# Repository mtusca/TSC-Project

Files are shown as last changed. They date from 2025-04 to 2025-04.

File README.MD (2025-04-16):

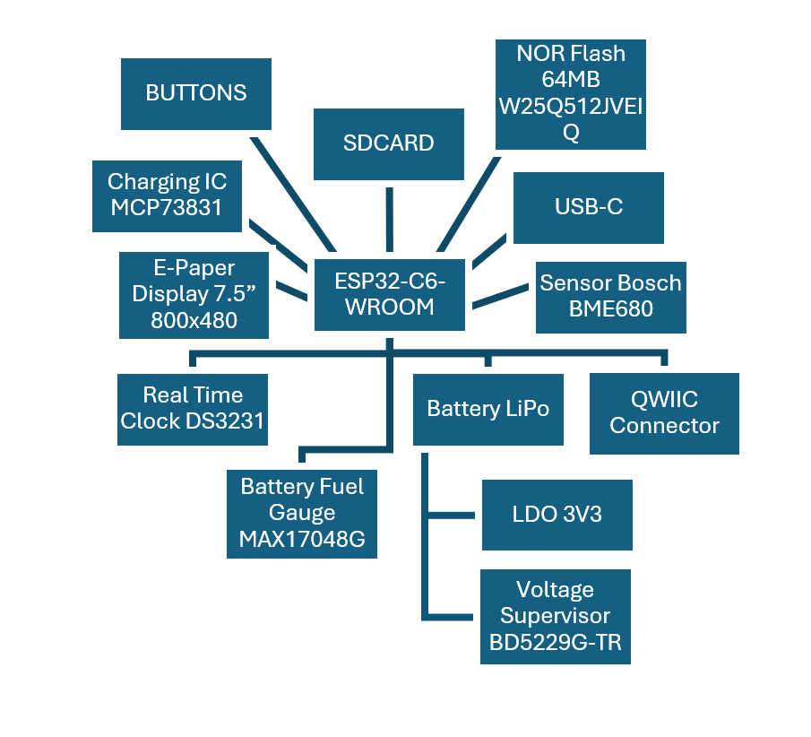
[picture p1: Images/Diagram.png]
Diagram


E-readerul implementat integrează mai multe module esențiale, inclusiv ESP32-C6, un modul RTC, senzori de mediu, 
conectivitate USB-C, un slot pentru card MicroSD și un sistem de gestionare a bateriei. 
Toate componentele comunică prin interfețe standard precum I²C, SPI, UART și GPIO analogice/digitale.

Controler de încărcare – MCP73831
Tip baterie: Li-ion/Li-Po cu o singură celulă

Curent de încărcare: Programabil până la 500 mA

Interfață: Standalone (fără I²C/SPI)

Tensiune de intrare: 3.75 V – 6 V

Ieșire stare: Indicație a stării de încărcare prin LED

Senzor de mediu – BME688
Măsurători: Temperatură, umiditate, presiune, gaze (VOC, calitatea aerului)

Interfață: I²C, SPI

Interval temperatură: -40 °C – +85 °C

Senzor de gaze: Detecție AI a amestecurilor de gaze și VOC

Consum de energie: Ultra redus (ideal pentru dispozitive mobile/wearables)

Display e-paper
Interfață: SPI

Rezoluție: 800×480

Consum de energie: Foarte redus (consum doar în timpul actualizării)

Caracteristici: Lizibil excelent în lumină solară, unghiuri largi de vizualizare

Conector Qwiic
Tip: Conector JST SH cu 4 pini (1.0 mm)

Scop: Interconectare I²C standardizată pentru senzori/module

Tensiune: Logică de 3.3 V

Pini: SDA, SCL, VCC, GND

Conector card memorie – 112A-TAAR-R03
Tip: Slot pentru card MicroSD

Interfață: SPI sau SDIO

Tensiune: Logică 3.3 V

Caracteristici: Mecanism push-push, contact pentru detectare card

Utilizare: Stocare de date, redare media

Microcontroler – ESP32-C6-WROOM-1-N8
Procesor: RISC-V pe 32 de biți, până la 160 MHz

Memorie: 512 KB SRAM intern, 8 MB flash extern (W25Q512JVEIQ)

Conectivitate: Wi-Fi 6 (802.11ax), Bluetooth 5 (LE), IEEE 802.15.4 (Thread/Zigbee), USB 2.0 (Full-Speed)

Periferice: SPI, I²C, UART, PWM, ADC, mai mulți pini GPIO

Memorie externă – W25Q512JVEIQ
Capacitate: 512 Mbit (64 MB)

Interfață: Quad SPI (QPI)

Frecvență de operare: Până la 133 MHz

Tensiune de alimentare: 2.7 V – 3.6 V

Caracteristici: rezistență mare (100.000 cicluri scriere/ștergere)

Ceas în timp real – DS3231SN#
Precizie: ±2 ppm între 0°C și +40°C

Interfață: I²C

Caracteristici: Oscilator cu cristal compensat termic (TCXO) integrat

Tensiune de funcționare: 2.3 V – 5.5 V

Funcționalități suplimentare: suport pentru baterie de rezervă, 2 alarme programabile, ieșire pătrată 1Hz

Monitor baterie – MAX17048G+T10
Funcție: Indicator de încărcare pentru baterii Li-ion/Li-Po cu o singură celulă

Interfață: I²C

Tensiune: 2.5 V – 4.5 V

Consum de putere: Curent de repaus ultra-redus (~23 µA)

<pre lang="markdown"> 
ESP32-C6 Pin description
  EN -> Resets the MCU
  IO0 - INT_RTC -> Used to receive interrupts signals from RTC, allowing for two major functionalities: Alarm and Square Wave Output
  IO1 - 32KHz -> Used for a stable clock signal of 32.768 kHz generated by the RTC
  IO2 – MISO -> Master In Slave Out Signal, used in the SPI communication with the SD Card
  IO3 - EPD_BUSY -> Indicates display driver status
  IO4 – SS_SD -> Chip select for SPI communication with SD Card
  IO5 – EPD_DC -> Display serial communication Command/Data input
  IO6 – SCK -> Clock signal for I2C communication
  IO7 – MOSI -> Master Out Slave In Signal, used to send data to display and SD Card
  IO8 - GPIO8 - Controls MCU boot mode
  IO9 - IO/BOOT -> Used to detect BOOT button press
  NC -> Not connected
  3V3 -> Used to power the MCU and the other components
  IO10 - EPD_CS -> Chip select for SPI serial communication with the display
  IO11 - FLASH_CS -> Chip select for SPI communication with the flash
  IO12 - USB_D- -> Used in USB differential communication
  IO13 - USB_D+ -> Used in USB differential communication
  IO15 - IO/CHANGE -> Used to detect CHANGE button press
  TXD0/GPIO16 - TX -> Sends data to another device via UART
  RXD0/GPIO17 - RX -> Receives data from another device via UART
  IO18 - RTC_RST -> Resets the RTC
  IO19 - I2C_PW -> Power source for I2C components
  IO20 - EPD_3V3_C -> Display IO voltage supply
  IO21 - SDA -> Used to send and receive data in the I2C communication with the sensor, RTC module and Battery Fuel Gauge
  IO22 - SCL -> Clock signal for I2C communication
  IO23 - EPD_RST -> Global reset signal for the display
  GND -> Shared Voltage Reference
</pre>

[📋 Download BoM](./Manufacturing/Bill%20of%20Materials.csv)

|Component |Footprint |Link |
|---|---|---|
|BOOT_BUTTON  |BUTTON_CUSYOMV1 |https://industry.panasonic.com/global/en/products/control/switch/light-touch/number/evqpuj02k |
|C1 |ESP32_WROVER_EAGLE-LTSPICE_CC0402 |https://eu.mouser.com/ProductDetail/YAGEO/CC0402MRX5R5BB106?qs=zEY9bCHj09eCmUJdZuS5Lg%3D%3D |
|C1_BAT |ESP32_WROVER_EAGLE-LTSPICE_CC0402 |n/a |
|C1_BAT1 |EAGLE-LTSPICE_CC0402 |n/a |
|C1_BAT2 |EAGLE-LTSPICE_CC0402 |n/a |
|C2 |ESP32_WROVER_EAGLE-LTSPICE_CC0402 |n/a |
|C2_BAT\ |ESP32_WROVER_EAGLE-LTSPICE_CC0402 |n/a |
|C3 |RCL_CPOL-EUCT3528 |n/a |
|C4 |ESP32_WROVER_EAGLE-LTSPICE_CC0402 |n/a |
|C4_USB |ESP32_WROVER_EAGLE-LTSPICE_CC0402 |n/a |
|C5 |ESP32_WROVER_EAGLE-LTSPICE_CC0402 |n/a |
|C5_USB |ESP32_WROVER_EAGLE-LTSPICE_CC0402 |n/a |
|C6 |ESP32_WROVER_EAGLE-LTSPICE_CC0402 |n/a |
|C7 |ESP32_WROVER_EAGLE-LTSPICE_CC0402 |n/a |
|C8 |ESP32_WROVER_EAGLE-LTSPICE_CC0402 |n/a |
|C9 |EAGLE-LTSPICE_CC0402 |n/a |
|C10 |ESP32_WROVER_EAGLE-LTSPICE_CC0402 |n/a |
|C10_SUPERCAP |CPH3225A |https://www.snapeda.com/parts/CPH3225A/Seiko+Instruments/view-part/?ref=eda |
|CHANGE_BUTTON|BUTTON_CUSYOMV1 |https://industry.panasonic.com/global/en/products/control/switch-light-touch/number/evqpuj02k |
|CHG_LED |ADAFRUIT_LEDCHIP-LED0603 |https://www.snapeda.com/parts/KP-1608SURCK/Kingbright/view-part/?ref=search&t=LED%200603 |
|C_DELAY |ESP32_WROVER_EAGLE-LTSPICE_CC0402 |n/a |
|D1 |USBLC6-2SC6Y |https://www.snapeda.com/parts/USBLC6-2SC6Y/STMicroelectronics/view-part/?ref=eda |
|D2 |ESP32_WROVER_AVX---SD0805S020S1R0_AVX_... |https://eu.mouser.com/ProductDetail/KYOCERA-AVX/SD0805S020S1R0?qs=jCA%252BPfw4LHbpkAoSnwrdjw%3D%3D |
|D3 |MBR0530 |https://eu.mouser.com/ProductDetail/KYOCERA-AVX/SD0805S020S1R0?qs=jCA%252BPfw4LHbpkAoSnwrdjw%3D%3D |
|D4 |MBR0530 |https://www.snapeda.com/parts/MBR0530/Onsemi/view-part/?ref=eda |
|D5 |MBR0530 |https://www.snapeda.com/parts/MBR0530/Onsemi/view-part/?ref=eda |
|D6 |PGB1010603MR |https://www.snapeda.com/parts/PGB1010603MR/Littelfuse/view-part/?ref=eda |
|D7 |ESP32_WROVER_AVX---SD0805S020S1R0_AVX_... |https://eu.mouser.com/ProductDetail/KYOCERA-AVX/SD0805S020S1R0?qs=jCA%252BPfw4LHbpkAoSnwrdjw%3D%3D |
|D8 |PGB1010603MR |https://www.snapeda.com/parts/PGB1010603MR/Littelfuse/view-part/?ref=eda |
|D9 |PGB1010603MR |https://www.snapeda.com/parts/PGB1010603MR/Littelfuse/view-part/?ref=eda |
|D10 |PGB1010603MR |https://www.snapeda.com/parts/PGB1010603MR/Littelfuse/view-part/?ref=eda |
|D11 |PGB1010603MR |https://www.snapeda.com/parts/PGB1010603MR/Littelfuse/view-part/?ref=eda |
|D12 |PGB1010603MR |https://www.snapeda.com/parts/PGB1010603MR/Littelfuse/view-part/?ref=eda |
|EPD_C1 |ESP32_WROVER_EAGLE-LTSPICE_CC0402 |n/a |
|EPD_C2 |ESP32_WROVER_EAGLE-LTSPICE_CC0402 |n/a |
|EPD_C5 |ESP32_WROVER_EAGLE-LTSPICE_CC0402 |n/a |
|EPD_C6 |ESP32_WROVER_EAGLE-LTSPICE_CC0402 |n/a |
|EPD_C7 |ESP32_WROVER_EAGLE-LTSPICE_CC0402 |n/a |
|EPD_C8 |ESP32_WROVER_EAGLE-LTSPICE_CC0402 |n/a |
|EPD_C9 |ESP32_WROVER_EAGLE-LTSPICE_CC0402 |n/a |
|EPD_C10 |ESP32_WROVER_EAGLE-LTSPICE_CC0402 |n/a |
|EPD_C11 |ESP32_WROVER_EAGLE-LTSPICE_CC0402 |n/a |
|EPD_C12 |ESP32_WROVER_EAGLE-LTSPICE_CC0402 |n/a |
|IC1 |BD5229G-TR |https://componentsearchengine.com/part-view/BD5229G-TR/ROHM%20Semiconductor |
|IC4 |XC6220A331MR-G |https://componentsearchengine.com/part-view/XC6220A331MR-G/Torex |
|J1 |FH34SRJ-24S-0.5SH_99_ |https://componentsearchengine.com/part-view/XC6220A331MR-G/Torex |
|J2 |SAMACSYS_PARTS_USB4110-GF-A |https://componentsearchengine.com/part-view/USB4110-GF-A/GCT%20(GLOBAL%20CONNECTOR%20TECHNOLOGY |
|J3 |QWIIC_CONNECTORJS-1MM |n/a |
|J4 |112A-TAAR-R03_ATTEND |https://store.comet.srl.ro/Catalogue/Product/43497/ |
|L1 |744043680IND_4828-WE-TPC_WRE |https://eu.mouser.com/ProductDetail/Wurth-Elektronik/744043680?qs=PGXP4M47uW6VkZq%252BkzjrHA%3D%3D |
|PFMF.050.1 |ESP32C6_VARISTORCN1812 |https://www.mouser.co.uk/ProductDetail/EPCOS-TDK/B72520T0350K062?qs=dEfas%2FXlABIszF52uu7vrg%3D%3D |
|Q1 |ESP32_WROVER_SPARKFUN-DISCRETESEMI_MOSFET_...|https://componentsearchengine.com/part-view/DMG2305UX-7/Diodes%20Incorporated |
|Q2 |ESP32_WROVER_SPARKFUN-DISCRETESEMI_MOSFET_...|n/a |
|Q3 |D8 |https://componentsearchengine.com/part-view/SI1308EDL-T1-GE3/Vishay |
|R1 |ESP32_WROVER_EAGLE-LTSPICE_RR0402 |n/a |
|R1-PINH |ESP32_WROVER_EAGLE-LTSPICE_RR0402 |n/a |
|R1-PINH1 |ESP32_WROVER_EAGLE-LTSPICE_RR0402 |n/a |
|R1_BAT |ESP32_WROVER_EAGLE-LTSPICE_RR0402 |n/a |
|R1_PWRUSB |ESP32_WROVER_EAGLE-LTSPICE_RR0402 |n/a |
|R2 |ESP32_WROVER_EAGLE-LTSPICE_RR0402 |https://componentsearchengine.com/part-view/R0402%201%25%20100%20K%20(RC0402FR-07100KL |
|R2-PINH |ESP32_WROVER_EAGLE-LTSPICE_RR0402 |n/a |
|R2-PINH1 |ESP32_WROVER_EAGLE-LTSPICE_RR0402 |n/a |
|R2-USB |ESP32_WROVER_EAGLE-LTSPICE_RR0402 |n/a |
|R2-USB1 |ESP32_WROVER_EAGLE-LTSPICE_RR0402 |n/a |
|R2_BAT |ESP32_WROVER_EAGLE-LTSPICE_RR0402 |n/a |
|R3 |ESP32_WROVER_EAGLE-LTSPICE_RR0402 |n/a |
|R4 |ESP32_WROVER_EAGLE-LTSPICE_RR0402 |n/a |
|R5 |ESP32_WROVER_EAGLE-LTSPICE_RR0402 |n/a |
|R6 |ESP32_WROVER_EAGLE-LTSPICE_RR0402 |n/a |
|R7 |ESP32_WROVER_EAGLE-LTSPICE_RR0402 |n/a |
|R8 |ESP32_WROVER_EAGLE-LTSPICE_RR0402 |n/a |
|R9 |ESP32_WROVER_EAGLE-LTSPICE_RR0402 |n/a |
|R10 |ESP32_WROVER_EAGLE-LTSPICE_RR0402 |n/a |
|RESET_BUTTON |BUTTON_CUSYOMV1 |https://industry.panasonic.com/global/en/products/control/switch/light-touch/number/evqpuj02k |
|R_BOOT |ESP32_WROVER_EAGLE-LTSPICE_RR0402 |n/a |
|R_CAPACITOR  |ESP32_WROVER_EAGLE-LTSPICE_RR0402 |n/a |
|R_CHANGE |ESP32_WROVER_EAGLE-LTSPICE_RR0402 |n/a |
|R_CL1 |ESP32_WROVER_EAGLE-LTSPICE_RR0402 |n/a |
|R_RESET |ESP32_WROVER_EAGLE-LTSPICE_RR0402 |n/a |
|SENSOR2 |ESP32_WROVER_BME680_BME680 |https://www.snapeda.com/parts/BME680/Bosch/view-part/?welcome=home |
|SJ1 |SJ |https://grabcad.com/library/solder-jumpers-1 |
|U1 |W25Q512JVEIQ |https://www.snapeda.com/parts/W25Q512JVEIQ/Winbond+Electronics/view-part/?ref=eda |
|U2 |ESP32-C6-WROOM-1-N8 |https://www.snapeda.com/parts/ESP32-C6-WROOM-1-N8/Espressif+Systems/view-part/?ref=eda |
|U3 |DS3231SN# |https://www.snapeda.com/parts/DS3231SN%23/Analog+Devices/view-part/?ref=eda |
|U4 |MAX17048G+T10 |https://www.snapeda.com/parts/MAX17048G+T10/Analog+Devices/view-part/?ref=eda |
|U5 |ESP32_WROVER_SPARKFUN-IC-POWER_MCP73831 |https://eu.mouser.com/ProductDetail/Microchip-Technology/MCP73831T-2ACI-OT?qs=yUQqVecv4qvbBQBGbHx0Mw%3D%3Dcf|

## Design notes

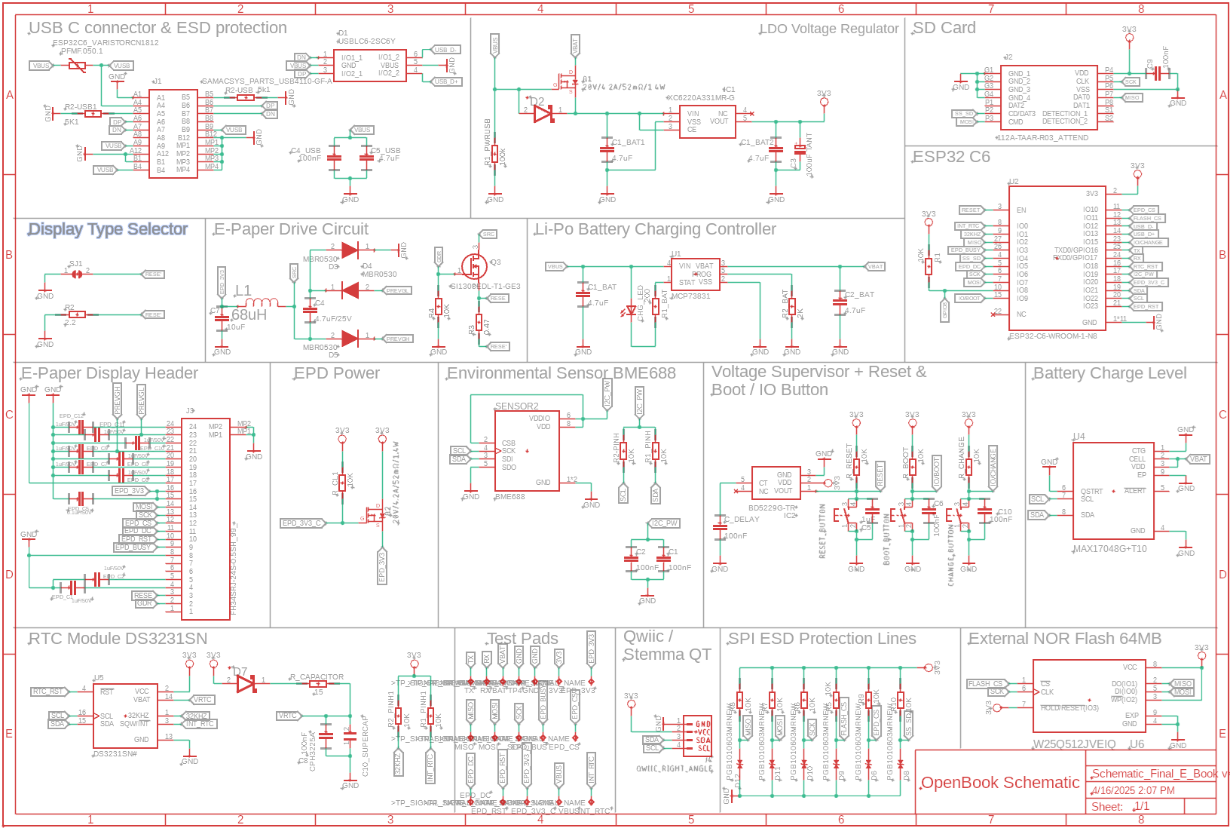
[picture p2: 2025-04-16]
Images/Schematic.png

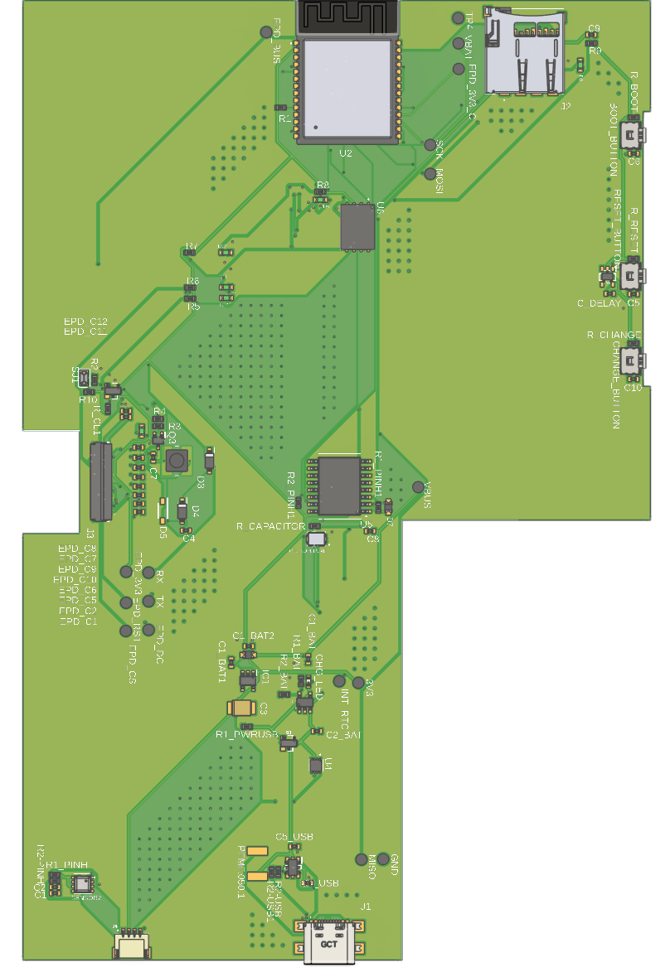
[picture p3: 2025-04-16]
Images/3D_PCB.png

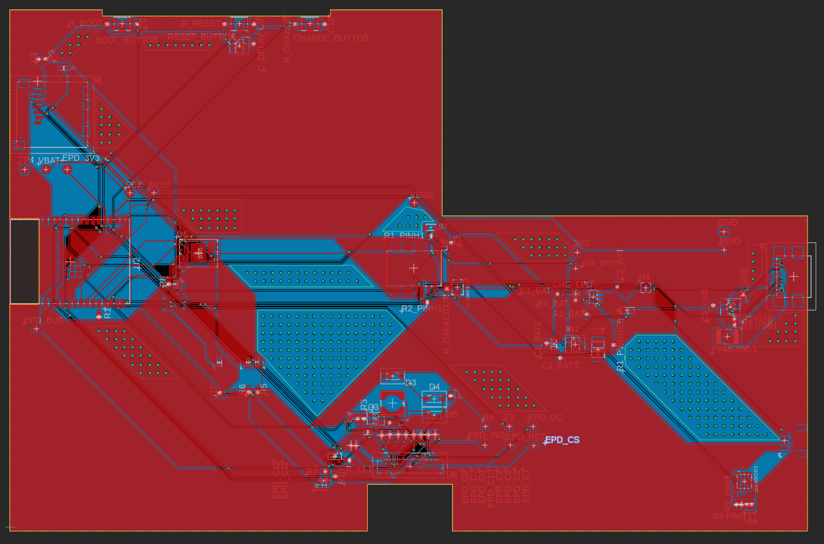
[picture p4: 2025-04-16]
Images/PCB.png

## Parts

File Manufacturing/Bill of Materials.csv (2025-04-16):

Qty | Value | Device | Package | Parts | Description | ARROW_PART_NUMBER | ARROW_PRICE-STOCK | AVAILABILITY | CENTROID_NOT_SPECIFIED | CHECK_PRICES | COPYRIGHT | DATASHEET | DESCRIPTION | DIGIKEY_DESCRIPTION | DIGIKEY_PART_NUMBER | HEIGHT | LEAD_FREE | MANUFACTURER_NAME | MANUFACTURER_PART_NUMBER | MF | MFR_NAME | MOUSER_PART_NUMBER | MOUSER_PRICE-STOCK | MOUSER_TESTING_PART_NUMBER | MOUSER_TESTING_PRICE-STOCK | MP | MPN | PACKAGE | POPULARITY | PREFIX | PRICE | PROD_ID | PURCHASE-URL | ROHS | SNAPEDA_LINK | SPICEPREFIX | TEMPERATURE_RANGE_HIGH | TEMPERATURE_RANGE_LOW | VALUE
1 |  | ADAFRUIT_LEDCHIP-LED0603 | ADAFRUIT_CHIP-LED0603 | CHG_LED | LED
1 |  | SJ | SJ | SJ1 | SMD solder JUMPER |  |  |  |  |  |  |  |  |  |  |  |  |  |  |  |  |  |  |  |  |  |  |  | 3
1 | 0.1uF/50V | ESP32_WROVER_EAGLE-LTSPICE_C | ESP32_WROVER_EAGLE-LTSPICE_C0402 | EPD_C5 | CAPACITOR, European symbol
1 | 0.47 | ESP32_WROVER_EAGLE-LTSPICE_R | ESP32_WROVER_EAGLE-LTSPICE_R0402 | R3 | RESISTOR, European symbol
1 | 100k | ESP32_WROVER_EAGLE-LTSPICE_R | ESP32_WROVER_EAGLE-LTSPICE_R0402 | R1_PWRUSB | RESISTOR, European symbol
8 | 100nF | ESP32_WROVER_EAGLE-LTSPICE_C | ESP32_WROVER_EAGLE-LTSPICE_C0402 | C1, C2, C4_USB, C6, C8, C9, C10, C_DELAY | CAPACITOR, European symbol
1 | 100uF TANT | RCL_CPOL-EUCT3528 | RCL_CT3528 | C3 | POLARIZED CAPACITOR, European symbol |  |  |  |  |  |  |  |  |  |  |  |  |  |  |  |  |  |  |  |  |  |  |  | 0 |  |  |  |  |  |  | C
16 | 10K | ESP32_WROVER_EAGLE-LTSPICE_R | ESP32_WROVER_EAGLE-LTSPICE_R0402 | R1, R1_PINH, R1_PINH1, R2-PINH, R2_PINH1, R4, R5, R6, R7, R8, R9, R10, R_BOOT, R_CHANGE, R_CL1, R_RESET | RESISTOR, European symbol
1 | 10uF | ESP32_WROVER_EAGLE-LTSPICE_C | ESP32_WROVER_EAGLE-LTSPICE_C0402 | C7 | CAPACITOR, European symbol
1 | 112A-TAAR-R03_ATTEND | 112A-TAAR-R03_ATTEND | 112ATAARR03ATTEND | J2 | Micro SD Card Socket, Push-Push Type, Top Mount, SMT, H=1.83mm, 10u |  |  |  |  |  |  |  | Micro SD Card Socket | Push-Push Type | Top Mount | SMT | H=1.83mm | 10u |  |  | 1.9mm |  | ATTEND | 112A-TAAR-R03 ATTEND
1 | 15 | ESP32_WROVER_EAGLE-LTSPICE_R | ESP32_WROVER_EAGLE-LTSPICE_R0402 | R_CAPACITOR | RESISTOR, European symbol
1 | 1uF | ESP32_WROVER_EAGLE-LTSPICE_C | ESP32_WROVER_EAGLE-LTSPICE_C0402 | C5 | CAPACITOR, European symbol
9 | 1uF/50V | ESP32_WROVER_EAGLE-LTSPICE_C | ESP32_WROVER_EAGLE-LTSPICE_C0402 | EPD_C1, EPD_C2, EPD_C6, EPD_C7, EPD_C8, EPD_C9, EPD_C10, EPD_C11, EPD_C12 | CAPACITOR, European symbol
1 | 2.2 | ESP32_WROVER_EAGLE-LTSPICE_R | ESP32_WROVER_EAGLE-LTSPICE_R0402 | R2 | RESISTOR, European symbol
1 | 200 | ESP32_WROVER_EAGLE-LTSPICE_R | ESP32_WROVER_EAGLE-LTSPICE_R0402 | R1_BAT | RESISTOR, European symbol
2 | 20V/4.2A/52m?/1.4W | ESP32_WROVER_SPARKFUN-DISCRETESEMI_MOSFET_PCH-DMG2305UX-7 | ESP32_WROVER_SPARKFUN-DISCRETESEMI_SOT23-3 | Q1, Q2 | P-channel MOSFETs |  |  |  |  |  |  |  |  |  |  |  |  |  |  |  |  |  |  |  |  |  |  |  |  |  |  | TRAN-14388 |  |  |  |  |  |  | 20V/4.2A/52m?/1.4W
1 | 2K | ESP32_WROVER_EAGLE-LTSPICE_R | ESP32_WROVER_EAGLE-LTSPICE_R0402 | R2_BAT | RESISTOR, European symbol
5 | 4.7uF | ESP32_WROVER_EAGLE-LTSPICE_C | ESP32_WROVER_EAGLE-LTSPICE_C0402 | C1_BAT, C1_BAT1, C1_BAT2, C2_BAT, C5_USB | CAPACITOR, European symbol
1 | 4.7uF/25V | ESP32_WROVER_EAGLE-LTSPICE_C | ESP32_WROVER_EAGLE-LTSPICE_C0402 | C4 | CAPACITOR, European symbol
1 | 5K1 | ESP32_WROVER_EAGLE-LTSPICE_R | ESP32_WROVER_EAGLE-LTSPICE_R0402 | R2-USB1 | RESISTOR, European symbol
1 | 5k1 | ESP32_WROVER_EAGLE-LTSPICE_R | ESP32_WROVER_EAGLE-LTSPICE_R0402 | R2-USB | RESISTOR, European symbol
1 | 68uH | 744043680IND_4828-WE-TPC_WRE | IND_4828-WE-TPC_WRE | L1 |  |  |  |  |  |  | Copyright (C) 2024 Ultra Librarian. All rights reserved. |  |  |  |  |  |  |  | 744043680 |  | Wurth Electronics
1 | BD5229G-TR | BD5229G-TR | SOT95P280X125-5N | IC2 | Voltage Detector with Adjustable Delay Time: CMOS processes are utilized to develop high precision, low current consumption CMOS reset ICs that allow arbitrary setting of the delay time. The extensive lineup includes both Nch Open Drain and CMOS output types in a wide range of detection voltages (from 2.3V to 6.0V, in 0.1V steps), enabling selection of the ideal solution based on customer requirements. In addition, the entire series is of course both lead-free and RoHS-compliant. |  |  |  |  |  |  |  | Voltage Detector with Adjustable Delay Time: CMOS processes are utilized to develop high precision | low current consumption CMOS reset ICs that allow arbitrary setting of the delay time. The extensive lineup includes both Nch Open Drain and CMOS output types in a wide range of detection voltages (from 2.3V to 6.0V | in 0.1V steps) | enabling selection of the ideal solution based on customer requirements. In addition | the entire series is of course both lead-free and RoHS-compliant. |  |  | 1.25mm |  | ROHM Semiconductor | BD5229G-TR |  |  | 755-BD5229G-TR | https://www.mouser.co.uk/ProductDetail/ROHM-Semiconductor/BD5229G-TR?qs=4kLU8WoGk0vvnhrrYwdszw%3D%3D
3 | BUTTON_CUSYOMV1NEW | BUTTON_CUSYOMV1NEW | MYBUTTON | BOOT_BUTTON, CHANGE_BUTTON, RESET_BUTTON
1 | CPH3225A | CPH3225A | CAPCP3225X100N | C10_SUPERCAP | Cap 0.011F 3.3V 1210 Flat Check availability |  |  | Not in stock |  | https://www.snapeda.com/parts/CPH3225A/Seiko+Instruments/view-part/?ref=eda |  |  | 11 mF (EDLC) Supercapacitor 3.3 V 1210 (3225 Metric) - - |  |  |  |  |  |  | Seiko Instruments |  |  |  |  |  | CPH3225A |  | 1210 Seiko |  |  | None |  | https://www.snapeda.com/api/url_track_click_mouser/?unipart_id=562593&manufacturer=Seiko Instruments&part_name=CPH3225A&search_term=None |  | https://www.snapeda.com/parts/CPH3225A/Seiko+Instruments/view-part/?ref=snap
1 | DS3231SN# | DS3231SN# | SOIC127P1032X265-16N | U5 | Real Time Clock Serial 16-Pin SOIC W T/R Check availability |  |  | In Stock |  | https://www.snapeda.com/parts/DS3231SN%23/Analog+Devices/view-part/?ref=eda |  |  | Extremely Accurate I?C-Integrated RTC/TCXO/Crystal |  |  |  |  |  |  | Analog Devices |  |  |  |  |  | DS3231SN# |  | SOIC-16 Maxim |  |  | None |  | https://www.snapeda.com/api/url_track_click_mouser/?unipart_id=99048&manufacturer=Analog Devices&part_name=DS3231SN#&search_term=None |  | https://www.snapeda.com/parts/DS3231SN%23/Analog+Devices/view-part/?ref=snap
1 | ESP32-C6-WROOM-1-N8 | ESP32-C6-WROOM-1-N8 | XCVR_ESP32-C6-WROOM-1-N8 | U2 | Check availability |  |  | In Stock |  | https://www.snapeda.com/parts/ESP32-C6-WROOM-1-N8/Espressif+Systems/view-part/?ref=eda |  |  | Multiprotocol Modules ESP32-C6 module | Wi-Fi 6 in 2.4 GHz band | Bluetooth 5 | Zigbee 3.0 and Thread. ESP34-WROOM Compatible - ENGINEERING SAMPLE |  |  |  |  |  |  | Espressif Systems |  |  |  |  |  | ESP32-C6-WROOM-1-N8 |  | None |  |  | None |  |  |  | https://www.snapeda.com/parts/ESP32-C6-WROOM-1-N8/Espressif+Systems/view-part/?ref=snap
1 | ESP32C6_VARISTORCN1812 | ESP32C6_VARISTORCN1812 | ESP32C6_VARISTOR_CT/CN1812 | PFMF.050.1 | VARISTOR |  |  |  |  |  |  |  |  |  |  |  |  |  |  |  |  |  |  |  |  |  |  |  | 0
2 | ESP32_WROVER_AVX---SD0805S020S1R0_AVX_SD0805S020S1R0_0_0AVX_SD0805S020S1R0_0_0 | ESP32_WROVER_AVX---SD0805S020S1R0_AVX_SD0805S020S1R0_0_0AVX_SD0805S020S1R0_0_0 | ESP32_WROVER_AVX---SD0805S020S1R0_AVX_SD0805S020S1R0_0 | D2, D7 | Schottky Barrier Rectifier Diode |  |  |  | No |  |  | http://datasheets.avx.com/schottky.pdf |  | DIODE SCHOTTKY 20V 1A 0805 | 478-7800-1-ND |  | yes |  |  | AVX |  | 581-SD0805S020S1R0 |  |  |  |  |  | 0805 (2012 metric) |  | D |  |  |  | yes |  |  | +125°C | -55°C
1 | ESP32_WROVER_BME680_BME680 | ESP32_WROVER_BME680_BME680 | ESP32_WROVER_BME680_PSON80P300X300X100-8N | SENSOR2 | Integrated Environmental Unit |  |  | Unavailable |  |  |  |  | Integrated Environmental Unit |  |  |  |  |  |  | Bosch Sensortec |  |  |  |  |  | BME680 |  | LGA-8 Bosch Tools |  |  | None
1 | ESP32_WROVER_SPARKFUN-IC-POWER_MCP73831 | ESP32_WROVER_SPARKFUN-IC-POWER_MCP73831 | ESP32_WROVER_SPARKFUN-IC-POWER_SOT23-5 | U1 | MCP73831T Li-Ion, Li-Pol Controller |  |  |  |  |  |  |  |  |  |  |  |  |  |  |  |  |  |  |  |  |  |  |  |  |  |  | IC-09995
1 | FH34SRJ-24S-0.5SH_99_ | FH34SRJ-24S-0.5SH_99_ | FH34SRJ24S05SH99 | J3 | (0.50mm) Surface Mount, Right Angle |  |  |  |  |  |  |  | 24 Position FFC | FPC Connector Contacts | (0.50mm) Surface Mount | Right Angle |  |  | 1.1mm |  | Hirose | FH34SRJ-24S-0.5SH(99) |  |  | 798-FH34SRJ24S05SH99 | https://www.mouser.co.uk/ProductDetail/Hirose-Connector/FH34SRJ-24S-0.5SH99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
1 | MAX17048G+T10 | MAX17048G+T10 | SON50P200X200X80-9N | U4 | Check availability |  |  | In Stock |  | https://www.snapeda.com/parts/MAX17048G+T10/Analog+Devices/view-part/?ref=eda |  |  | 3µA 1-Cell/2-Cell Fuel Gauge with ModelGauge |  |  |  |  |  |  | Analog Devices |  |  |  |  |  | MAX17048G+T10 |  | TDFN-8 Maxim |  |  | None |  | https://www.snapeda.com/api/url_track_click_mouser/?unipart_id=329239&manufacturer=Analog Devices&part_name=MAX17048G+T10&search_term=None |  | https://www.snapeda.com/parts/MAX17048G+T10/Analog+Devices/view-part/?ref=snap
3 | MBR0530 | MBR0530 | SOD3716X135N | D3, D4, D5 | ON SEMICONDUCTOR - MBR0530 - DIODE, SCHOTTKY, 0.5A, 30V, SOD-123 |  |  | In Stock |  | https://www.snapeda.com/parts/MBR0530/Onsemi/view-part/?ref=eda |  |  | Diode Schottky 30 V 500mA Surface Mount SOD-123 |  |  |  |  |  |  | ON Semiconductor |  |  |  |  |  | MBR0530 |  | SOD-123-2 ON Semiconductor |  |  | None |  | https://www.snapeda.com/api/url_track_click_mouser/?unipart_id=179458&manufacturer=ON Semiconductor&part_name=MBR0530&search_term=None |  | https://www.snapeda.com/parts/MBR0530/Onsemi/view-part/?ref=snap
6 | PGB1010603MRNEW | PGB1010603MRNEW | DIOC1608X36N | D6, D8, D9, D10, D11, D12 | Check availability
1 | QWIIC_RIGHT_ANGLE | QWIIC_CONNECTORJS-1MM | JST04_1MM_RA | J4 | SparkFun I2C Standard Qwiic Connector |  |  |  |  |  |  |  |  |  |  |  |  |  |  |  |  |  |  |  |  |  |  |  |  |  |  | CONN-13694 |  |  |  |  |  |  | QWIIC_RIGHT_ANGLE
1 | SAMACSYS_PARTS_USB4110-GF-A | SAMACSYS_PARTS_USB4110-GF-A | SAMACSYS_PARTS_USB4110GFA | J1 | CONN USB 2.0 TYPE-C R/A SMT |  |  |  |  |  |  |  | CONN USB 2.0 TYPE-C R/A SMT |  |  | 3.26mm |  | GCT (GLOBAL CONNECTOR TECHNOLOGY) | USB4110-GF-A |  |  | 640-USB4110-GF-A | https://www.mouser.co.uk/ProductDetail/GCT/USB4110-GF-A?qs=KUoIvG%2F9IlYiZvIXQjyJeA%3D%3D
1 | SI1308EDL-T1-GE3 | SI1308EDL-T1-GE3 | SOT65P210X110-3N | Q3 | MOSFET N-Ch 30V 1.5A TrenchFET SC70 Vishay Si1308EDL-T1-GE3 N-channel MOSFET Transistor, 1.5 A, 30 V, 3-Pin SC-70 |  |  | In Stock |  | https://www.snapeda.com/parts/SI1308EDL-T1-GE3/Vishay+Siliconix/view-part/?ref=eda |  |  | Si1308EDL-T1-GE3 N-channel MOSFET Transistor | 1.5 A | 30 V | 3-Pin SC-70 | Siliconix / Vishay SI1308EDL-T1-GE3 |  |  |  |  |  |  | Vishay Siliconix |  |  |  |  |  | SI1308EDL-T1-GE3 |  | SOT-323 Vishay Semiconductor |  |  | None |  | https://www.snapeda.com/api/url_track_click_mouser/?unipart_id=274603&manufacturer=Vishay Siliconix&part_name=SI1308EDL-T1-GE3&search_term=None |  | https://www.snapeda.com/parts/SI1308EDL-T1-GE3/Vishay+Siliconix/view-part/?ref=snap
17 | TP | TP | TP20R | TP1, TP2, TP3, TP4, TP5, TP6, TP7, TP8, TP9, TP10, TP11, TP12, TP13, TP14, TP15, TP16, TP17 | Test pad
1 | USBLC6-2SC6Y | USBLC6-2SC6Y | SOT95P280X145-6N | D1 | Low Cap. ESD Protection Auto SOT-23-6 STMicroelectronics USBLC6-2SC6Y, Dual Uni-Directional TVS Diode Array, 6-Pin SOT-23 |  |  | In Stock |  | https://www.snapeda.com/parts/USBLC6-2SC6Y/STMicroelectronics/view-part/?ref=eda |  |  | 17V Clamp 5A (8/20µs) Ipp Tvs Diode Surface Mount SOT-23-6 |  |  |  |  |  |  | STMicroelectronics |  |  |  |  |  | USBLC6-2SC6Y |  | SOT-23-6 STMicroelectronics |  |  | None |  |  |  | https://www.snapeda.com/parts/USBLC6-2SC6Y/STMicroelectronics/view-part/?ref=snap
1 | W25Q512JVEIQ | W25Q512JVEIQ | SON127P600X800X80-9N | U6 | Check availability |  |  | In Stock |  | https://www.snapeda.com/parts/W25Q512JVEIQ/Winbond+Electronics/view-part/?ref=eda |  |  | FLASH - NOR Memory IC 512Mb (64M x 8) SPI - Quad I/O 133 MHz 8-WSON (8x6) |  |  |  |  |  |  | Winbond Electronics |  |  |  |  |  | W25Q512JVEIQ |  | Package |  |  | None |  |  |  | https://www.snapeda.com/parts/W25Q512JVEIQ/Winbond+Electronics/view-part/?ref=snap
1 | XC6220A331MR-G | XC6220A331MR-G | SOT95P280X120-5N | IC1 | LDO Voltage Regulators |  |  |  |  |  |  |  | LDO Voltage Regulators |  |  | 1.2mm |  | Torex | XC6220A331MR-G |  |  | 865-XC6220A331MR-G | https://www.mouser.co.uk/ProductDetail/Torex-Semiconductor/XC6220A331MR-G?qs=AsjdqWjXhJ8ZSWznL1J0gg%3D%3D

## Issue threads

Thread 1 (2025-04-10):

[BUG] Component value is incorrect

crispy25, 2025-04-10:
Wrong value for the EPD_C5 component in the schematic.

It should be 0.1uF/50V and not 1uF/50V.

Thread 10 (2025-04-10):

[BUG] 90 Degree routes

crispy25, 2025-04-10:
The PCB contains 90 degree routes.

Examples:

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

Closed 2025-04-15.

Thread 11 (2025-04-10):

[BUG] PCB thickness

crispy25, 2025-04-10:
The PCB is too thick. It should be 1mm thick, not 1.6mm.

Hint: This can be changed via Layer Stack Menu from the Design Tab.

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

Closed 2025-04-15.

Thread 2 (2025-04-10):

[BUG] Component is not connected properly

crispy25, 2025-04-10:
The environmental sensor does not have VDD and VDDIO connected to I2C_PW.

It should look like this:

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

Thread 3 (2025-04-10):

[BUG] Labels are not named correctly

crispy25, 2025-04-10:
The USB Connector has pin connections with a wrong label name.

Please check the following pins:

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

The selected labels should be named VUSB.

Closed 2025-04-15.

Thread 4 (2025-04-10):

[DOCS] Missing components name

crispy25, 2025-04-10:
The environmental sensor and the battery charging controller do not have a component name in the schematic.

Closed 2025-04-15.

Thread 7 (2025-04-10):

[DOCS] README has incorrect informations

crispy25, 2025-04-10:
**Microcontroller pin usage section** has wrong information. Please check the ESP32 pins in the schematic and their usage.

**Bill of Materials section** has the following problems:
- Datasheet/Buy Link is not provided for component C3
- Buy Link is not provided for buttons
- Link leads to a wrong component: D3, J1
- Link leads to nothing: Resistors, U5
- Components with different values share the same Buy Link

Closed 2025-04-15.

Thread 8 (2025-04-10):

[BUG] PCB measurements use the wrong layer

crispy25, 2025-04-10:
Measurements are placed on the wrong layer, causing them to be printed on the silkscreen.

Example:

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

Please move them to their corresponding layer.

Closed 2025-04-15.

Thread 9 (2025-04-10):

[BUG] Power traces wrong width

crispy25, 2025-04-10:
Power traces (e.g., 3V3, EPD_3V3, VBUS) are currently 0.15 mm wide, but they should be 0.3 mm.

Closed 2025-04-15.

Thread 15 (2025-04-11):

[BUG] Display 3D Model incorrect dimensions

crispy25, 2025-04-11:
The base of the display should have 170.2mm.

Current version:

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

Datasheet specifications:

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

Closed 2025-04-16.

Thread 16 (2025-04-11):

[BUG] Via Stitching is missing

crispy25, 2025-04-11:
Please place stitching vias on the PCB, especially:
+ Near the ESP32 pins
+ Across the separation zones between GND planes

Example of separation zone:

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

Closed 2025-04-15.

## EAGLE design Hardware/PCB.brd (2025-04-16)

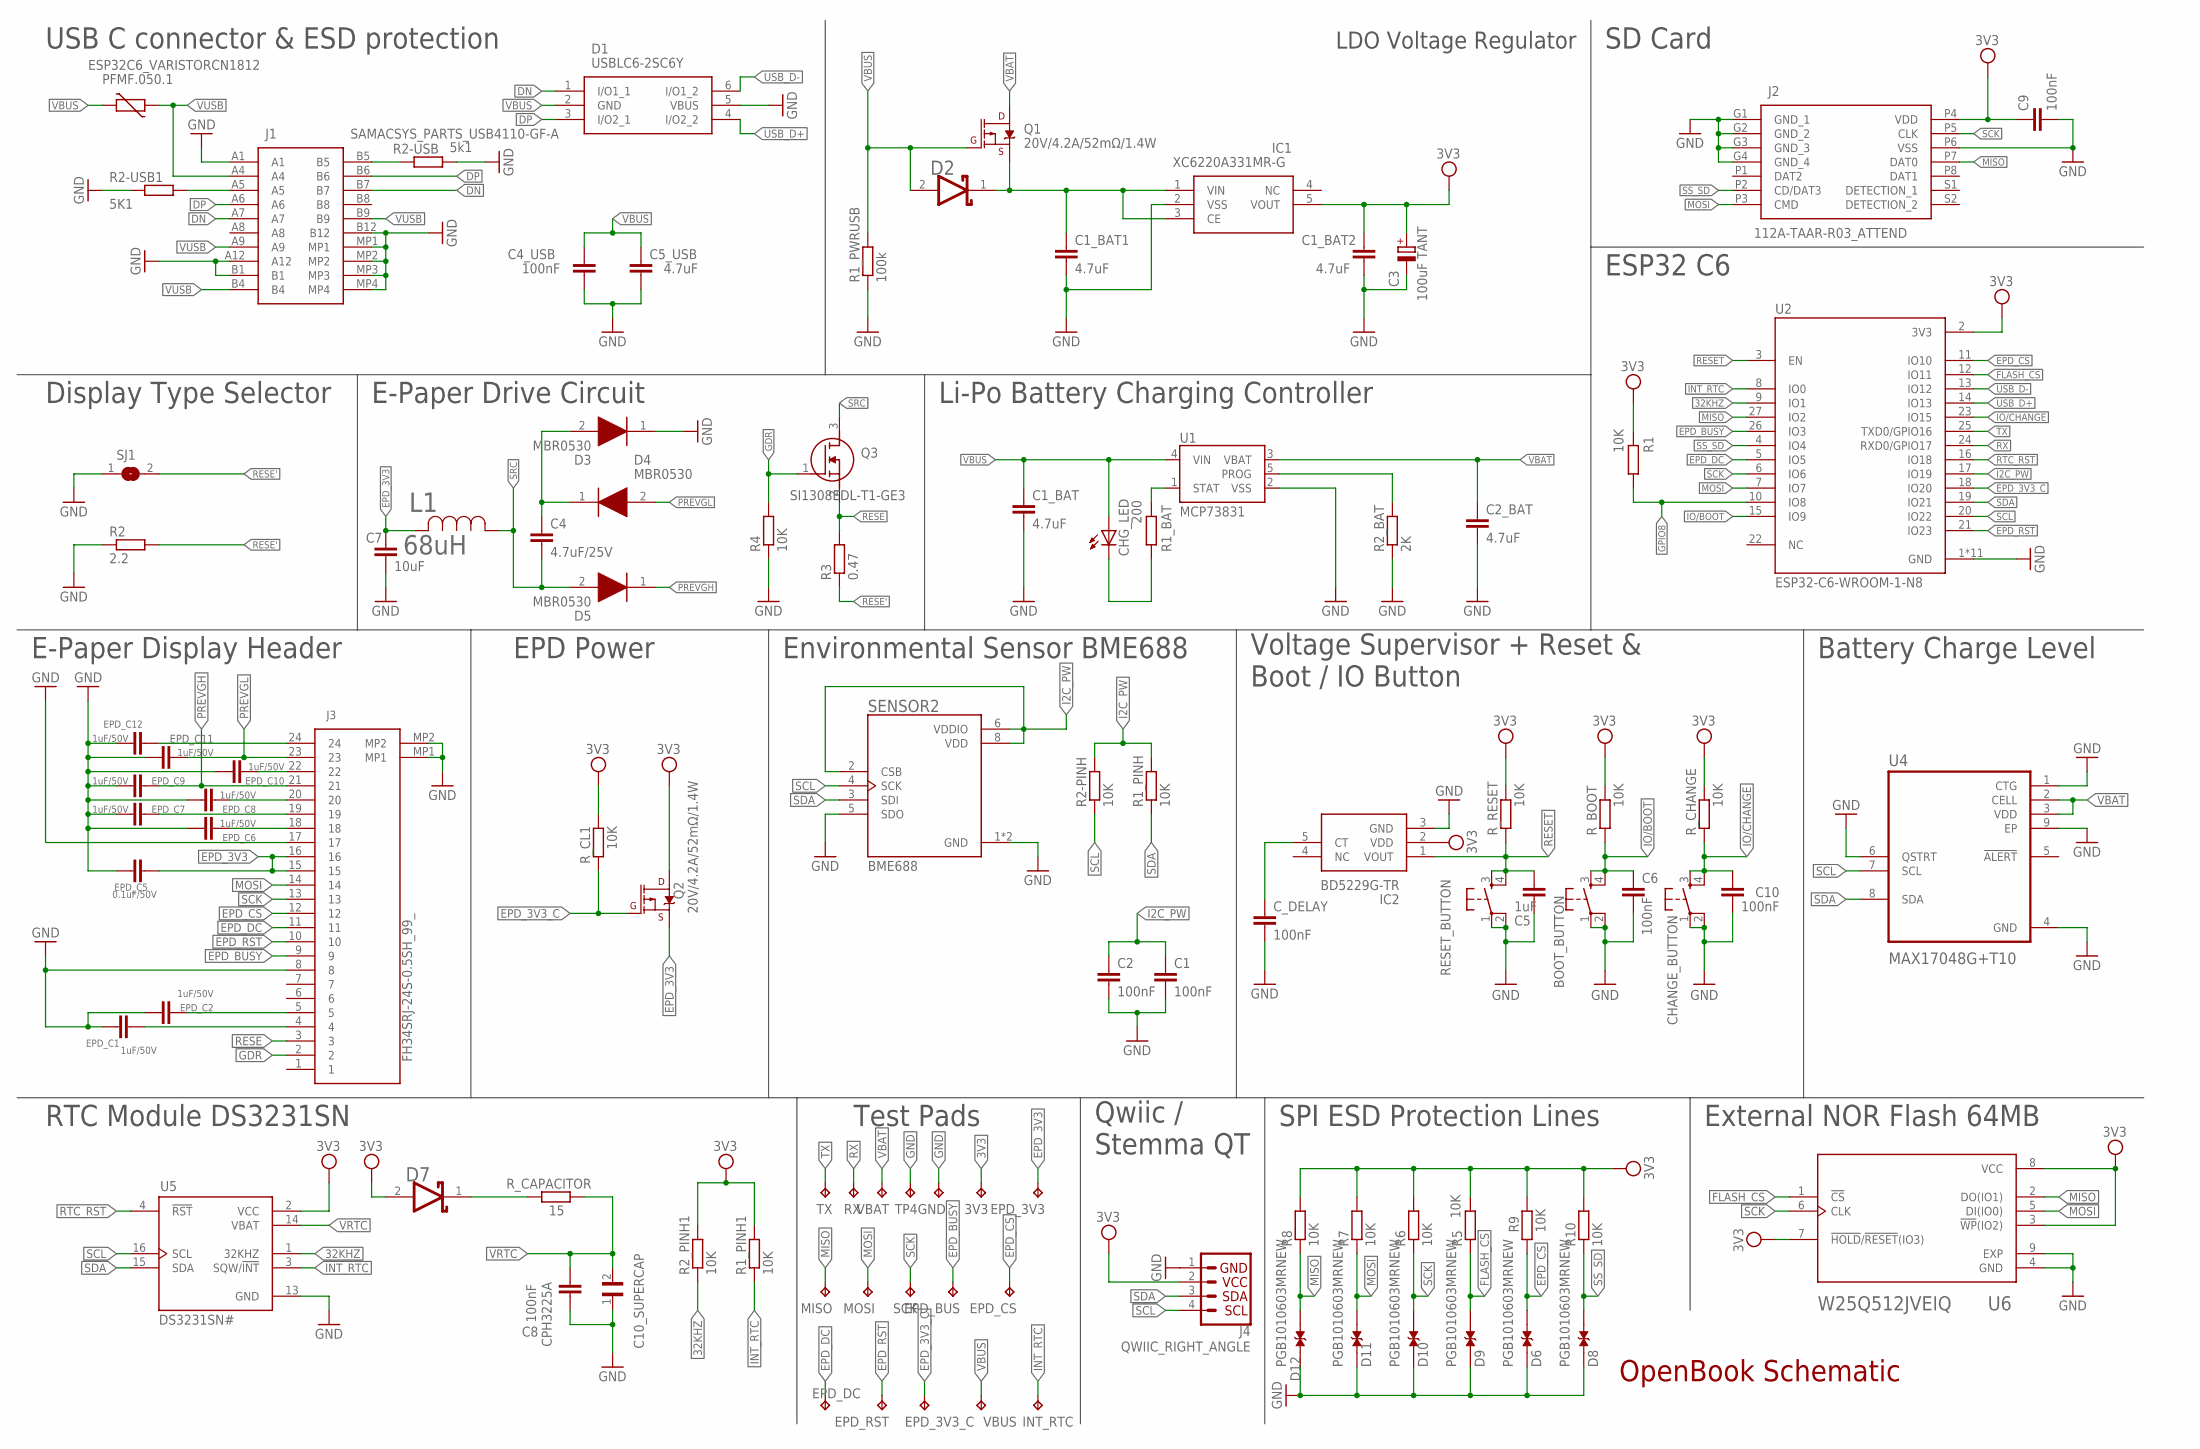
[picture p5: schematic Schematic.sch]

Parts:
3V3: TP; TP20R
BOOT_BUTTON: BUTTON_CUSYOMV1NEW; MYBUTTON
C1, C2, C4_USB, C6, C8, C9, C10: 100nF; ESP32_WROVER_EAGLE-LTSPICE_C0402
C1_BAT, C1_BAT1, C1_BAT2, C2_BAT, C5_USB: 4.7uF; ESP32_WROVER_EAGLE-LTSPICE_C0402
C3: 100uF TANT; RCL_CT3528
C4: 4.7uF/25V; ESP32_WROVER_EAGLE-LTSPICE_C0402
C5: 1uF; ESP32_WROVER_EAGLE-LTSPICE_C0402
C7: 10uF; ESP32_WROVER_EAGLE-LTSPICE_C0402
C10_SUPERCAP: CPH3225A; CAPCP3225X100N
CHANGE_BUTTON: BUTTON_CUSYOMV1NEW; MYBUTTON
CHG_LED: ADAFRUIT_LEDCHIP-LED0603; ADAFRUIT_CHIP-LED0603
C_DELAY: 100nF; ESP32_WROVER_EAGLE-LTSPICE_C0402
D1: USBLC6-2SC6Y; SOT95P280X145-6N
D2, D7: ESP32_WROVER_AVX---SD0805S020S1R0_AVX_SD0805S020S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; ESP32_WROVER_AVX---SD0805S020S1R0_AVX_SD0805S020S1R0_0
D3, D4, D5: MBR0530; SOD3716X135N
D6, D8, D9, D10, D11, D12: PGB1010603MRNEW; DIOC1608X36N
EPD_3V3, EPD_3V3_C: TP; TP20R
EPD_BUS: TP; TP20R
EPD_C1, EPD_C2, EPD_C6, EPD_C7, EPD_C8, EPD_C9, EPD_C10, EPD_C11, EPD_C12: 1uF/50V; ESP32_WROVER_EAGLE-LTSPICE_C0402
EPD_C5: 0.1uF/50V; ESP32_WROVER_EAGLE-LTSPICE_C0402
EPD_CS: TP; TP20R
EPD_DC: TP; TP20R
EPD_RST: TP; TP20R
GND: TP; TP20R
IC1: XC6220A331MR-G; SOT95P280X120-5N
IC2: BD5229G-TR; SOT95P280X125-5N
INT_RTC: TP; TP20R
J1: SAMACSYS_PARTS_USB4110-GF-A; SAMACSYS_PARTS_USB4110GFA
J2: 112A-TAAR-R03_ATTEND; 112ATAARR03ATTEND
J3: FH34SRJ-24S-0.5SH_99_; FH34SRJ24S05SH99
J4: QWIIC_RIGHT_ANGLE; JST04_1MM_RA
L1: 68uH; IND_4828-WE-TPC_WRE
MISO: TP; TP20R
MOSI: TP; TP20R
PFMF.050.1: ESP32C6_VARISTORCN1812; ESP32C6_VARISTOR_CT/CN1812
Q1, Q2: 20V/4.2A/52mΩ/1.4W; ESP32_WROVER_SPARKFUN-DISCRETESEMI_SOT23-3
Q3: SI1308EDL-T1-GE3; SOT65P210X110-3N
R1, R1_PINH, R1_PINH1, R2-PINH, R2_PINH1, R4, R5, R6, R7, R8, R9, R10: 10K; ESP32_WROVER_EAGLE-LTSPICE_R0402
R1_BAT: 200; ESP32_WROVER_EAGLE-LTSPICE_R0402
R1_PWRUSB: 100k; ESP32_WROVER_EAGLE-LTSPICE_R0402
R2: 2.2; ESP32_WROVER_EAGLE-LTSPICE_R0402
R2-USB: 5k1; ESP32_WROVER_EAGLE-LTSPICE_R0402
R2-USB1: 5K1; ESP32_WROVER_EAGLE-LTSPICE_R0402
R2_BAT: 2K; ESP32_WROVER_EAGLE-LTSPICE_R0402
R3: 0.47; ESP32_WROVER_EAGLE-LTSPICE_R0402
RESET_BUTTON: BUTTON_CUSYOMV1NEW; MYBUTTON
RX: TP; TP20R
R_BOOT: 10K; ESP32_WROVER_EAGLE-LTSPICE_R0402
R_CAPACITOR: 15; ESP32_WROVER_EAGLE-LTSPICE_R0402
R_CHANGE: 10K; ESP32_WROVER_EAGLE-LTSPICE_R0402
R_CL1: 10K; ESP32_WROVER_EAGLE-LTSPICE_R0402
R_RESET: 10K; ESP32_WROVER_EAGLE-LTSPICE_R0402
SCK: TP; TP20R
SENSOR2: ESP32_WROVER_BME680_BME680; ESP32_WROVER_BME680_PSON80P300X300X100-8N
SJ1: SJ
TP4: TP; TP20R
TX: TP; TP20R
U1: ESP32_WROVER_SPARKFUN-IC-POWER_MCP73831; ESP32_WROVER_SPARKFUN-IC-POWER_SOT23-5
U2: ESP32-C6-WROOM-1-N8; XCVR_ESP32-C6-WROOM-1-N8
U4: MAX17048G+T10; SON50P200X200X80-9N
U5: DS3231SN#; SOIC127P1032X265-16N
U6: W25Q512JVEIQ; SON127P600X800X80-9N
VBAT: TP; TP20R
VBUS: TP; TP20R

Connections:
3V3: 3V3.TP, C1_BAT2.1, C3.+, C9.1, D7.2 (ANODE), IC1.5 (VOUT), IC2.2 (VDD), J2.P4 (VDD), J4.2, Q2.3 (D), R1.2, R1_PINH1.2, R2_PINH1.2, R5.2, R6.2, R7.2, R8.2, R9.2, R10.2, R_BOOT.2, R_CHANGE.2, R_CL1.2, R_RESET.2, U2.2 (3V3), U5.2 (VCC), U6.3 (!WP!(IO2)), U6.7 (!HOLD!/!RESET!(IO3)), U6.8 (VCC)
32KHZ: R2_PINH1.1, U2.9 (IO1), U5.1 (32KHZ)
DN: D1.1 (I/O1_1), J1.A7, J1.B7
DP: D1.3 (I/O2_1), J1.A6, J1.B6
EPD_3V3: C7.1, EPD_3V3.TP, EPD_C5.2, J3.15, J3.16, L1.2, Q2.2 (S)
EPD_3V3_C: EPD_3V3_C.TP, Q2.1 (G), R_CL1.1, U2.18 (IO20)
EPD_BUSY: EPD_BUS.TP, J3.9, U2.26 (IO3)
EPD_CS: D6.1 (2), EPD_CS.TP, J3.12, R9.1, U2.11 (IO10)
EPD_DC: EPD_DC.TP, J3.11, U2.5 (IO5)
EPD_RST: EPD_RST.TP, J3.10, U2.21 (IO23)
FLASH_CS: D9.1 (2), R5.1, U2.12 (IO11), U6.1 (!CS)
GDR: J3.2, Q3.1 (G), R4.2
GND: BOOT_BUTTON.1, BOOT_BUTTON.2, C1.2, C1_BAT.2, C1_BAT1.2, C1_BAT2.2, C2.2, C2_BAT.2, C3.-, C4_USB.2, C5.2, C5_USB.2, C6.2, C7.2, C8.2, C9.2, C10.2, C10_SUPERCAP.1, CHANGE_BUTTON.1, CHANGE_BUTTON.2, C_DELAY.2, D1.5 (VBUS), D3.1 (K), D6.2 (1), D8.2 (1), D9.2 (1), D10.2 (1), D11.2 (1), D12.2 (1), EPD_C1.1, EPD_C2.1, EPD_C5.1, EPD_C6.1, EPD_C7.1, EPD_C8.1, EPD_C9.1, EPD_C10.1, EPD_C11.1, EPD_C12.1, GND.TP, IC1.2 (VSS), IC2.3 (GND), J1.A1, J1.A12, J1.B1, J1.B12, J1.MP1, J1.MP2, J1.MP3, J1.MP4, J2.G1 (GND_1), J2.G2 (GND_2), J2.G3 (GND_3), J2.G4 (GND_4), J2.P6 (VSS), J3.8, J3.17, J3.MP1, J3.MP2, J4.1, R1_PWRUSB.1, R2.1, R2-USB.2, R2-USB1.1, R2_BAT.1, R4.1, RESET_BUTTON.1, RESET_BUTTON.2, SENSOR2.1 (GND), SENSOR2.5 (SDO), SENSOR2.7 (GND), SJ1.1, TP4.TP, U1.2 (VSS), U2.1 (GND), U2.28 (GND), U2.29_1 (GND), U2.29_2 (GND), U2.29_3 (GND), U2.29_4 (GND), U2.29_5 (GND), U2.29_6 (GND), U2.29_7 (GND), U2.29_8 (GND), U2.29_9 (GND), U4.1 (CTG), U4.4 (GND), U4.6 (QSTRT), U4.9 (EP), U5.13 (GND), U6.4 (GND), U6.9 (EXP)
GPIO8: R1.1, U2.10 (IO8)
I2C_PW: C1.1, C2.1, R1_PINH.2, R2-PINH.2, SENSOR2.2 (CSB), SENSOR2.6 (VDDIO), SENSOR2.8 (VDD), U2.17 (IO19)
INT_RTC: INT_RTC.TP, R1_PINH1.1, U2.8 (IO0), U5.3 (SQW/!INT)
IO/BOOT: BOOT_BUTTON.3, BOOT_BUTTON.4, C6.1, R_BOOT.1, U2.15 (IO9)
IO/CHANGE: C10.1, CHANGE_BUTTON.3, CHANGE_BUTTON.4, R_CHANGE.1, U2.23 (IO15)
MISO: D12.1 (2), J2.P7 (DAT0), MISO.TP, R8.1, U2.27 (IO2), U6.2 (DO(IO1))
MOSI: D11.1 (2), J2.P3 (CMD), J3.14, MOSI.TP, R7.1, U2.7 (IO7), U6.5 (DI(IO0))
unnamed: EPD_C12.2, J3.24
unnamed: C1_BAT1.1, D2.1 (CATHODE), IC1.1 (VIN), IC1.3 (CE), Q1.2 (S)
unnamed: J1.A5, R2-USB1.2
unnamed: CHG_LED.C, R1_BAT.1
unnamed: C4.1, D3.2 (A), D4.1 (K)
unnamed: R1_BAT.2, U1.1 (STAT)
unnamed: R2_BAT.2, U1.5 (PROG)
unnamed: EPD_C10.2, J3.22
unnamed: C_DELAY.1, IC2.5 (CT)
unnamed: J1.B5, R2-USB.1
unnamed: EPD_C8.2, J3.20
unnamed: EPD_C7.2, J3.19
unnamed: EPD_C6.2, J3.18
unnamed: D7.1 (CATHODE), R_CAPACITOR.1
unnamed: EPD_C2.2, J3.5
unnamed: EPD_C1.2, J3.4
PREVGH: D5.1 (K), EPD_C9.2, J3.21
PREVGL: D4.2 (A), EPD_C11.2, J3.23
RESE: J3.3, Q3.2 (S), R3.2
RESE': R2.2, R3.1, SJ1.2
RESET: C5.1, IC2.1 (VOUT), RESET_BUTTON.3, RESET_BUTTON.4, R_RESET.1, U2.3 (EN)
RTC_RST: U2.16 (IO18), U5.4 (!RST)
RX: RX.TP, U2.24 (RXD0/GPIO17)
SCK: D10.1 (2), J2.P5 (CLK), J3.13, R6.1, SCK.TP, U2.6 (IO6), U6.6 (CLK)
SCL: J4.4, R2-PINH.1, SENSOR2.4 (SCK), U2.20 (IO22), U4.7 (SCL), U5.16 (SCL)
SDA: J4.3, R1_PINH.1, SENSOR2.3 (SDI), U2.19 (IO21), U4.8 (SDA), U5.15 (SDA)
SRC: C4.2, D5.2 (A), L1.1, Q3.3 (D)
SS_SD: D8.1 (2), J2.P2 (CD/DAT3), R10.1, U2.4 (IO4)
TX: TX.TP, U2.25 (TXD0/GPIO16)
USB_D+: D1.4 (I/O2_2), U2.14 (IO13)
USB_D-: D1.6 (I/O1_2), U2.13 (IO12)
VBAT: C2_BAT.1, Q1.3 (D), U1.3 (VBAT), U4.2 (CELL), U4.3 (VDD), VBAT.TP
VBUS: C1_BAT.1, C4_USB.1, C5_USB.1, CHG_LED.A, D1.2 (GND), D2.2 (ANODE), PFMF.050.1.2, Q1.1 (G), R1_PWRUSB.2, U1.4 (VIN), VBUS.TP
VRTC: C8.1, C10_SUPERCAP.2, R_CAPACITOR.2, U5.14 (VBAT)
VUSB: J1.A4, J1.A9, J1.B4, J1.B9, PFMF.050.1.1

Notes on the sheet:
USB C connector & ESD protection
Display Type Selector
E-Paper Drive Circuit
LDO Voltage Regulator
SD Card
Li-Po Battery Charging Controller
E-Paper Display Header
EPD Power
Environmental Sensor BME688
Voltage Supervisor + Reset & Boot / IO Button
Battery Charge Level
RTC Module DS3231SN
Test Pads
Qwiic / Stemma QT
External NOR Flash 64MB
SPI ESD Protection Lines
OpenBook Schematic
ESP32 C6
BME688
MCP73831

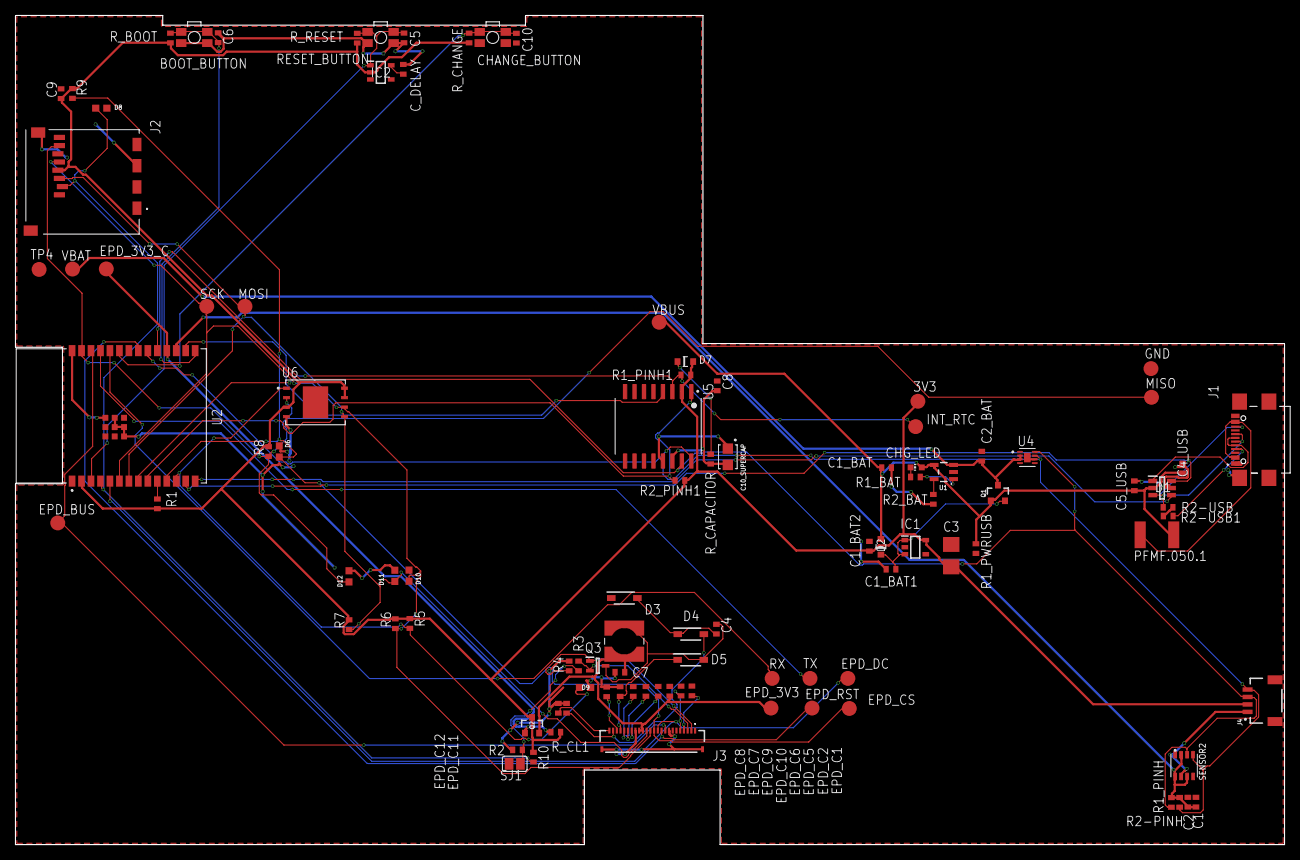
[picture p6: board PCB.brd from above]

Board: 2 copper layers, 170.2 x 111.2 mm, 103 parts (0 on the bottom side), 55 nets.

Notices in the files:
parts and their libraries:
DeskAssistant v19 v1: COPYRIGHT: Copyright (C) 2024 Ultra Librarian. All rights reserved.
